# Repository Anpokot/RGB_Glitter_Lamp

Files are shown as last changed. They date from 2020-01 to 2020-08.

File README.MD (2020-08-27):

## RGB Glitter Lamp Project

### 3D Views

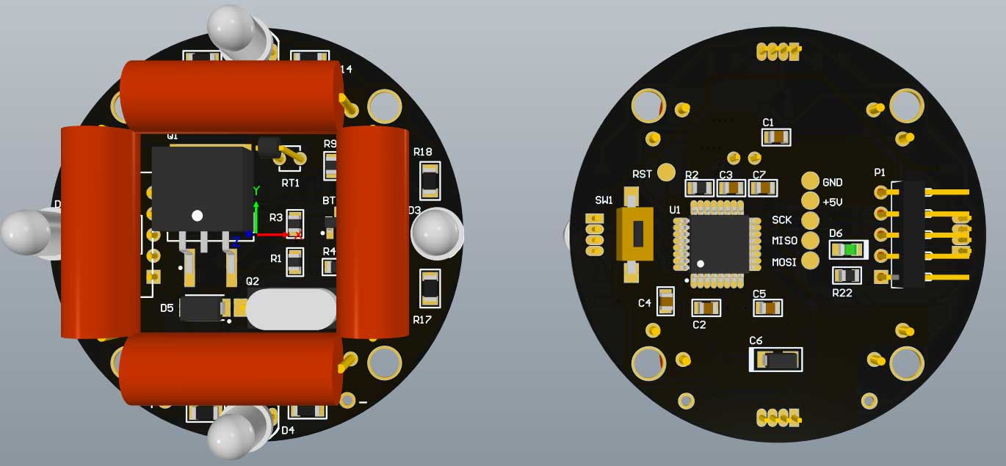
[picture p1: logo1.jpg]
</br>

### Top and Bottom View

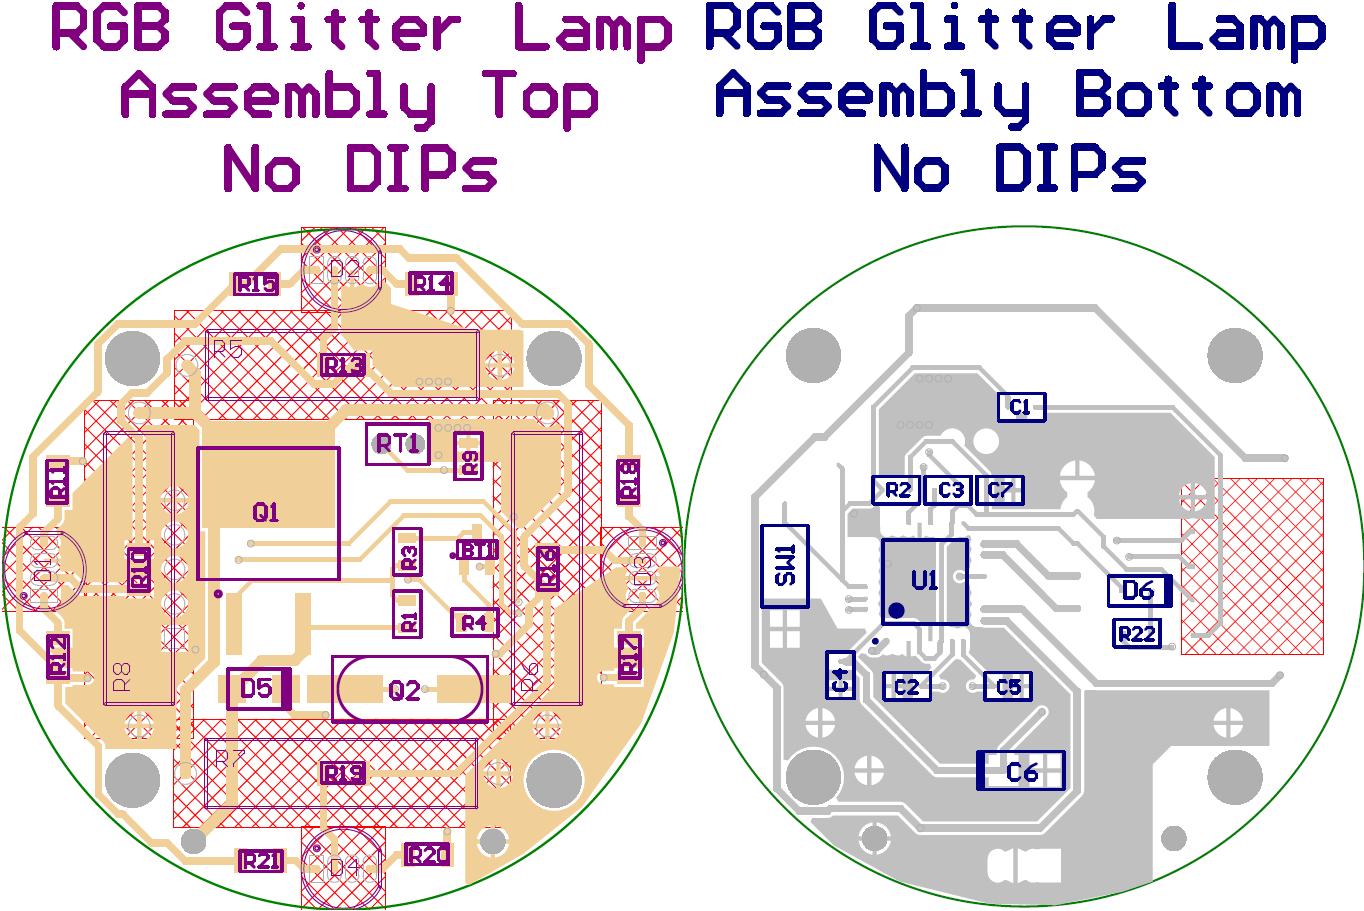
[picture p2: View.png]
</br>

### Assembly Views

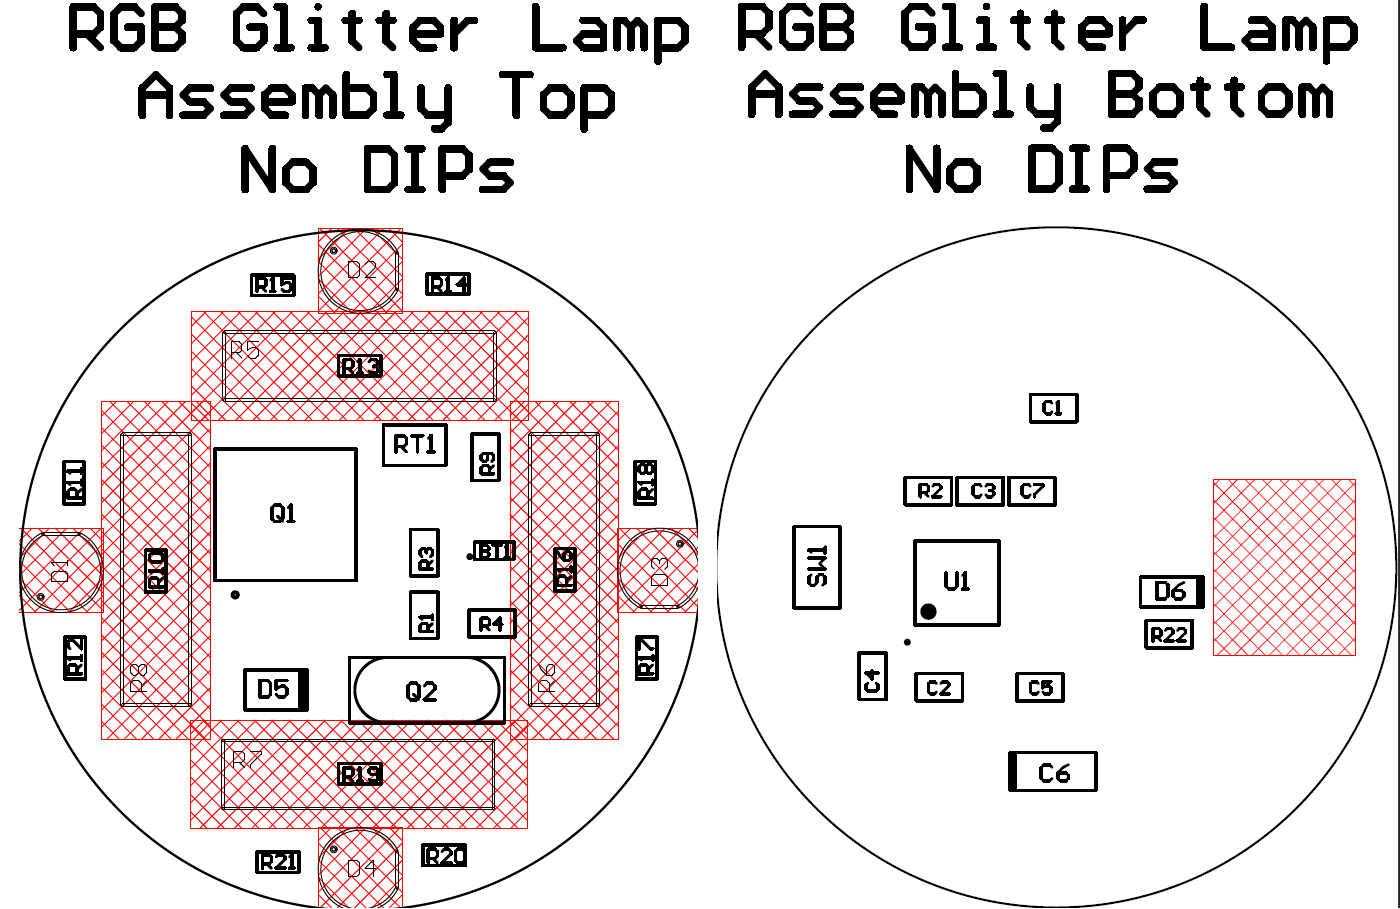
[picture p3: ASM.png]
</br>

### Mechanical Views

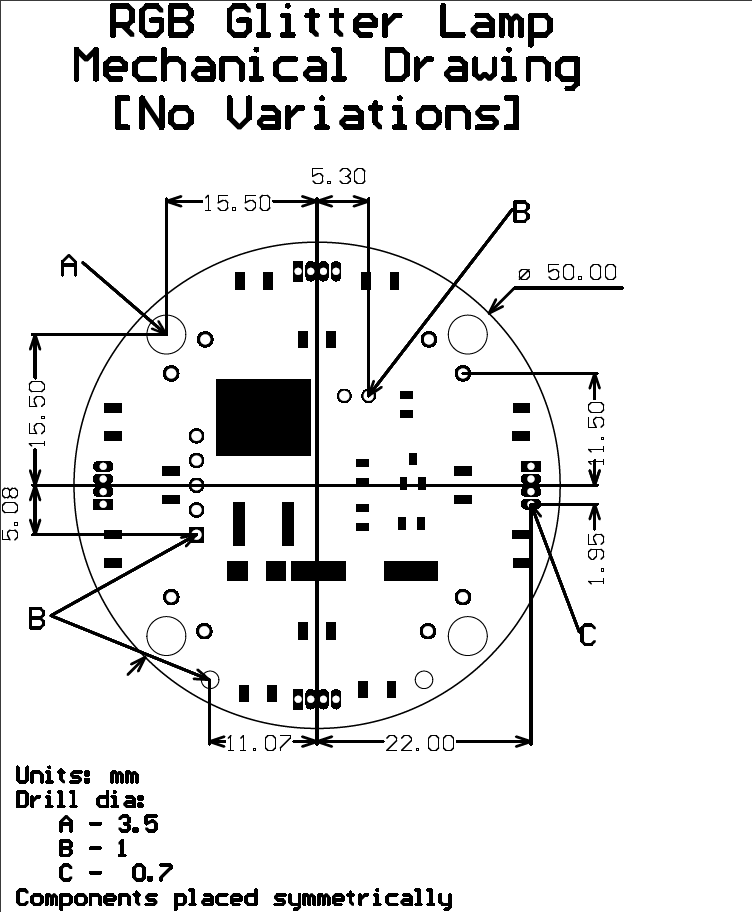
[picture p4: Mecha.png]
</br>

### Schematic

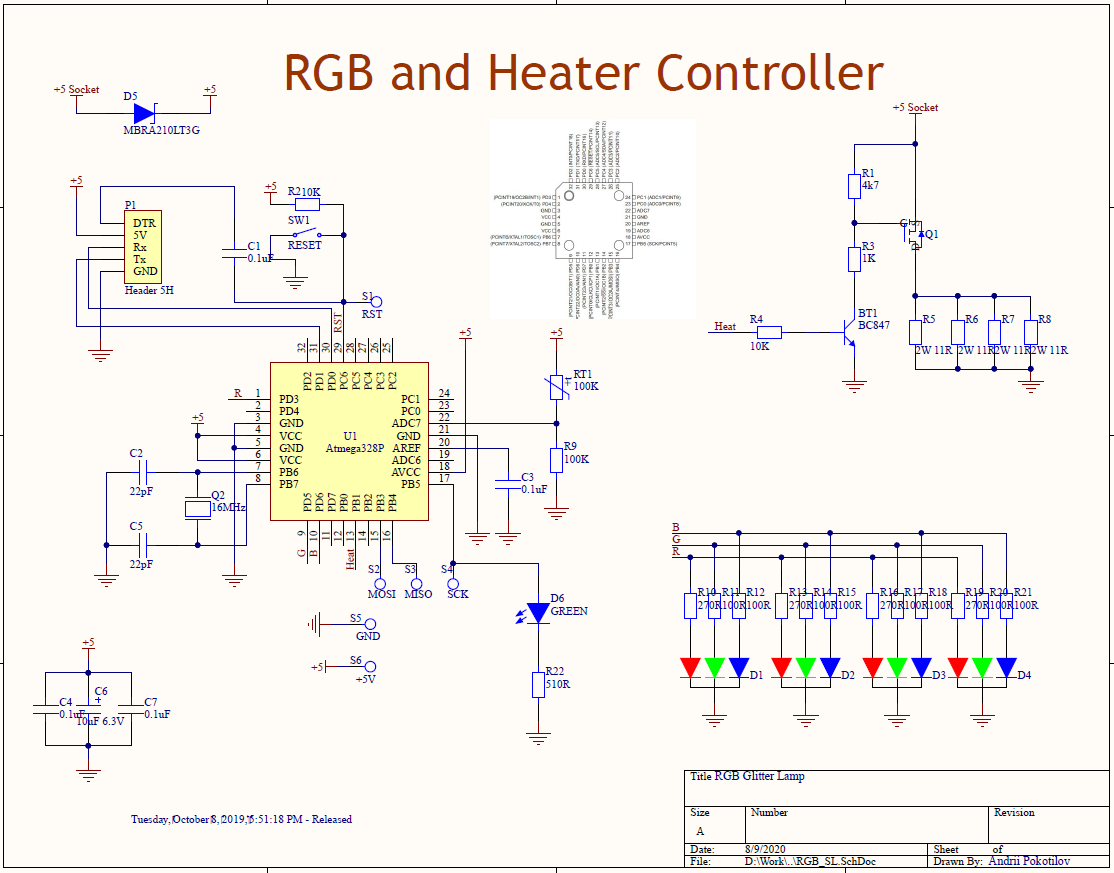
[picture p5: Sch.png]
</br>

### History

Inspiered by this video [Gillian's Diamonds lamp](https://youtu.be/PCyUxlsRoRc?t=2872) I decided to create my own version with extra features</br>

Atmega328 is used to control RGB lights and heater. 2W resistors used as a heater and thermistor provides temperature feedback</br>

Demo video of assembled prototype:</br>
Glitter Lamp Demo (https://www.youtube.com/watch?v=RdrIAsrwDjk)</br>

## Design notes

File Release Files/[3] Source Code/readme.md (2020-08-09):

## RGB Glitter Lamp Project

### Code description

ALA librarry provides defferent animations for RGB LED's </br>
Animation selection using rotary encoder with interrupts and temperature control with no delay </br>
Filtering provides valid input and allows to use low quality ecoders</br>

### Thanks to
Arduino Light Animation (ALA) library - Bruno Portaluri - bportaluri.com</br>
Robust Rotary encoder reading - John Main - best-microcontroller-projects.com

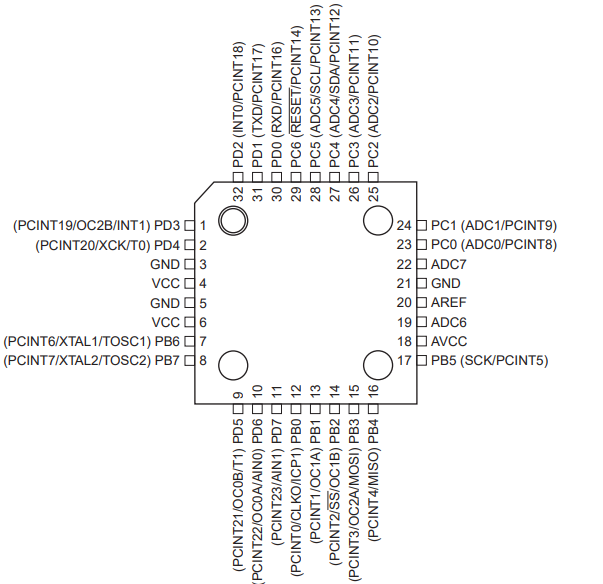
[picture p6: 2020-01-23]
Capture.PNG

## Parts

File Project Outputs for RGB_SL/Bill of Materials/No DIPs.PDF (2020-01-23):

Component | list

### Source Data From: RGB_SL.PrjPcb

Project: | RGB_SL.PrjPcb
Variant: | No DIPs
Report Date: | 11/11/2019 | 2:30:49 PM

### Print Date: 11-Nov-19 2:30:53 PM

# | Category | Manufacturer 1 | Manufacturer Part Number 1 | Case/Package | Description | Quantity

1 | Capacitors | Vishay Sprague | 293D106X96R3A2TE3 | 1206 | CAP TANT 10UF 6.3V 10% 1206 | 1
2 | Capasitors | Vishay Vitramon | VJ0805Y104KXAAT | 0805 | Ceramic Cap 0.1uF 50 V 10% MLCC - SMD/SMT | 4
3 | Capasitors | Vishay | VJ0805A220JXACW1BC | 0805 | Ceramic Cap 22 pF 50 V ±5 % Tolerance C0G/NP0 SMT Multilayer | 2
4 | Crystals | ECS International | ECS-160-20-5PX-TR | HC-49/US | CRYSTAL 16.0000MHZ 20PF SMD | 1
5 | Diodes | ON Semiconductor | MBRA210LT3G | CASE 403D SMA | DIODE SCHOTTKY 10V 2A SMA | 1
6 | Integrated Circuits | Microchip | ATMEGA328P-AUR | TQFP | IC MCU 8BIT 32KB FLASH 32TQFP | 1
7 | MOSFETs | ON Semiconductor / Fairchild | NDP6020P | TO-220AB | MOSFET P-Ch LL FET Enhancement Mode | 1
8 | NTC Thermistors | Canadian Thermostats | MF52A1104J3950 | | THERMISTOR 100K OHM 5% BEAD | 1
9 | Optoelectronics | VCC CHML | CMD17-21VGD/TR8 | 0805 | LED GREEN DIFFUSED 0805 SMD | 1
10 | Resistors | Vishay | TNPW0805100KFEEA | 0805 | RES SMD 100K Ohm 1% 0.2W(1/5W) ±25ppm/C Sulfur Resistant Conformal Coated Pad SMD Automotive Medical T/R | 1
11 | Resistors | Vishay Dale | CRCW080510K0FKTA | 0805 | RES SMD 10K OHM 1% 1/8W 0805 | 2
12 | Resistors | Vishay Dale | CRCW08051K00FKEA | 0805 | RES SMD 1K OHM 1% 1/8W 0805 | 1
13 | Resistors | Vishay | CRCW08054K70JNEAC | 0805 | RES SMD 4.7K Ohm 5% 1/8W ±200ppm/°C Molded SMD Paper T/R | 1
14 | Resistors | Vishay | CRCW0805510RFKEA | 0805 | RES SMD 510 OHM 1% 1/8W 0805 | 1
15 | Resistors | Vishay Semiconductors | CRCW1206100RFKEAC | 1206 | RES SMD 100 OHM 1% 1/4W 1206 | 8
16 | Resistors | Vishay Semiconductors | CRCW1206270RFKEAC | 1206 | RES SMD 270 OHM 1% 1/4W 1206 | 4
17 | Sw itches | TE Connectivity | FSMSMTR | SMD/SMT | SWITCH TACTILE SPST-NO 0.05A 24V | 1
18 | Transistors | Infineon | BC847AE6327HTSA1 | SOT-23-3 | Trans NPN 45V 0.1A Automotive 3-Pin SOT-23 T/R GP BJT | 1
| | | | | | 33

### Comment

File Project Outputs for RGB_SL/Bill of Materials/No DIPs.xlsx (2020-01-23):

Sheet: Part List Report
 | Component list
 | Source Data From: | RGB_SL.PrjPcb
 | Project: | RGB_SL.PrjPcb
 | Variant: | No DIPs
 | Report Date: | 10/5/2019 | 4:22:37 PM
 | Print Date: | 2019-10-05 | 16:35:53
# | Category | Manufacturer 1 | Manufacturer Part Number 1 | Case/Package | Description | Quantity
1 | Capacitors | Vishay Sprague (https://octopart-clicks.com/click/altium?sku=718-1126-1-ND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) | 293D106X96R3A2TE3 (https://octopart-clicks.com/click/altium?sku=718-1126-1-ND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) | 1206 | CAP TANT 10UF 6.3V 10% 1206 | 1
2 | Capasitors | Vishay Vitramon (https://octopart-clicks.com/click/altium?sku=720-1383-1-ND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) | VJ0805Y104KXAAT (https://octopart-clicks.com/click/altium?sku=720-1383-1-ND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) | 0805 | Ceramic Cap 0.1uF 50 V 10% MLCC - SMD/SMT | 4
3 | Capasitors | Vishay (https://octopart-clicks.com/click/altium?sku=720-1601-1-ND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) | VJ0805A220JXACW1BC (https://octopart-clicks.com/click/altium?sku=720-1601-1-ND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) | 0805 | Ceramic Cap 22 pF 50 V ±5 % Tolerance C0G/NP0 SMT Multilayer | 2
4 | Crystals | ECS International (https://octopart-clicks.com/click/altium?sku=XC1282CT-ND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) | ECS-160-20-5PX-TR (https://octopart-clicks.com/click/altium?sku=XC1282CT-ND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) | HC-49/US | CRYSTAL 16.0000MHZ 20PF SMD | 1
5 | Diodes | ON Semiconductor (https://octopart-clicks.com/click/altium?sku=MBRA210LT3GOSCT-ND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) | MBRA210LT3G (https://octopart-clicks.com/click/altium?sku=MBRA210LT3GOSCT-ND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) | CASE 403D SMA | DIODE SCHOTTKY 10V 2A SMA | 1
6 | Integrated Circuits | Microchip (https://octopart-clicks.com/click/altium?sku=ATMEGA328P-AURCT-ND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) | ATMEGA328P-AUR (https://octopart-clicks.com/click/altium?sku=ATMEGA328P-AURCT-ND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) | TQFP | IC MCU 8BIT 32KB FLASH 32TQFP | 1
7 | MOSFETs | ON Semiconductor / Fairchild (https://octopart-clicks.com/click/altium?manufacturer=ON%20Semiconductor%20%2F%20Fairchild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) | NDP6020P (https://octopart-clicks.com/click/altium?manufacturer=ON%20Semiconductor%20%2F%20Fairchild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) | TO-220AB | MOSFET P-Ch LL FET Enhancement Mode | 1
8 | Optoelectronics | VCC CHML (https://octopart-clicks.com/click/altium?sku=L62505CT-ND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) | CMD17-21VGD/TR8 (https://octopart-clicks.com/click/altium?sku=L62505CT-ND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) | 0805 | LED GREEN DIFFUSED 0805 SMD | 1
9 | Resistors | Vishay (https://octopart-clicks.com/click/altium?sku=541-3912-1-ND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) | TNPW0805100KFEEA (https://octopart-clicks.com/click/altium?sku=541-3912-1-ND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) | 0805 | RES SMD 100K Ohm 1% 0.2W(1/5W) ±25ppm/C Sulfur Resistant Conformal Coated Pad SMD Automotive Medical T/R | 1
10 | Resistors | Vishay Dale (https://octopart-clicks.com/click/altium?sku=541-3016-1-ND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) | CRCW080510K0FKTA (https://octopart-clicks.com/click/altium?sku=541-3016-1-ND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) | 0805 | RES SMD 10K OHM 1% 1/8W 0805 | 2
11 | Resistors | Vishay Dale (https://octopart-clicks.com/click/altium?sku=541-1.00KCDKR-ND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) | CRCW08051K00FKEA (https://octopart-clicks.com/click/altium?sku=541-1.00KCDKR-ND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) | 0805 | RES SMD 1K OHM 1% 1/8W 0805 | 1
12 | Resistors | Vishay (https://octopart-clicks.com/click/altium?sku=541-4165-1-ND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) | CRCW08054K70JNEAC (https://octopart-clicks.com/click/altium?sku=541-4165-1-ND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) | 0805 | RES SMD 4.7K Ohm 5% 1/8W ±200ppm/°C Molded SMD Paper T/R | 1
13 | Resistors | Vishay (https://octopart-clicks.com/click/altium?sku=541-510CCT-ND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) | CRCW0805510RFKEA (https://octopart-clicks.com/click/altium?sku=541-510CCT-ND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) | 0805 | RES SMD 510 OHM 1% 1/8W 0805 | 1
14 | Resistors | Vishay Semiconductors (https://octopart-clicks.com/click/altium?manufacturer=Vishay%20Semiconductors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) | CRCW1206100RFKEAC (https://octopart-clicks.com/click/altium?manufacturer=Vishay%20Semiconductors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) | 1206 | RES SMD 100 OHM 1% 1/4W 1206 | 8
15 | Resistors | Vishay Semiconductors (https://octopart-clicks.com/click/altium?manufacturer=Vishay%20Semiconductors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) | CRCW1206270RFKEAC (https://octopart-clicks.com/click/altium?manufacturer=Vishay%20Semiconductors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) | 1206 | RES SMD 270 OHM 1% 1/4W 1206 | 4
16 | Switches | TE Connectivity (https://octopart-clicks.com/click/altium?sku=450-1758-6-ND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) | FSMSMTR (https://octopart-clicks.com/click/altium?sku=450-1758-6-ND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) | SMD/SMT | SWITCH TACTILE SPST-NO 0.05A 24V | 1
17 | Transistors | Infineon (https://octopart-clicks.com/click/altium?sku=BC847AE6327HTSA1CT-ND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) | BC847A (https://octopart-clicks.com/click/altium?sku=BC847AE6327HTSA1CT-ND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) | SOT-23-3 | Trans NPN 45V 0.1A Automotive 3-Pin SOT-23 T/R GP BJT | 1
 |  |  |  |  |  | 32
Comment

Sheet: Project Information
Project Full Path | D:\Work\Altium\My Projects\RGB_SL\RGB_SL.PrjPcb
Project Filename | RGB_SL.PrjPcb
Variant Name | No DIPs
Data-Source Filename | RGB_SL.PrjPcb
Data-Source Full Path | D:\Work\Altium\My Projects\RGB_SL\RGB_SL.PrjPcb
Title | <Parameter Title not found>
Total Quantity | 32
Report Time | 4:22:37 PM
Report Date | 10/5/2019
Report Date & Tine | 10/5/2019 4:22:37 PM
Output Name | Bill of Materials
Output Type | BOM_PartType
Output Generator Name | BOM
Output Generator Description | Bill of Materials

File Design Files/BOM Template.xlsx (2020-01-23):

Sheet: Part List Report
 | Component list
 | Source Data From: | Field=DataSourceFileName
 | Project: | Field=ProjectFileName
 | Variant: | Field=VariantName
 | Report Date: | Field=ReportDate | Field=ReportTime
 | Print Date: | 2019-10-05 | 15:03:10
# | Column=Category | Column=Manufacturer 1 | Column=Manufacturer Part Number 1 | Column=Case/Package | Column=Description | Column=Quantity
1
2
3
 |  |  |  |  |  | 0
Comment

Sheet: Project Information
Project Full Path | Field=ProjectFullPath
Project Filename | Field=ProjectFileName
Variant Name | Field=VariantName
Data-Source Filename | Field=DataSourceFileName
Data-Source Full Path | Field=DataSourceFullPath
Title | Field=Title
Total Quantity | Field=TotalQuantity
Report Time | Field=ReportTime
Report Date | Field=ReportDate
Report Date & Tine | Field=ReportDateTime
Output Name | Field=OutputName
Output Type | Field=OutputType
Output Generator Name | Field=GeneratorName
Output Generator Description | Field=GeneratorDescription

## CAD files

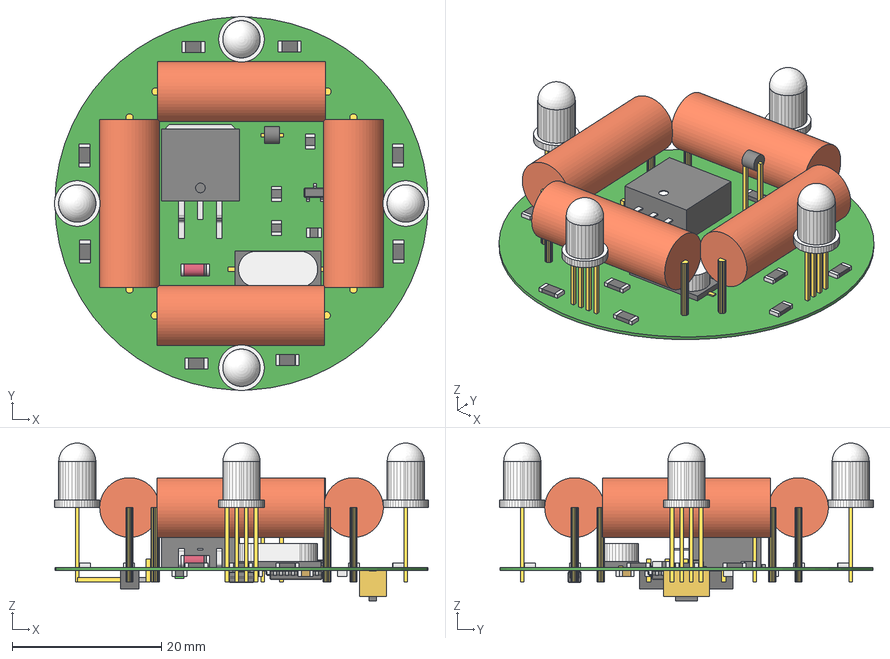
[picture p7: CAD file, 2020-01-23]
Project Outputs for RGB_SL/Export STEP/[No Variations].step
50.1 x 50.1 x 21.2 mm
Board
Open_CASCADE_STEP_translator_6.8_4.1.1
Lead x 4
Extruded x 133
Open_CASCADE_STEP_translator_6.8_25.1.1
Leader x 35
Open_CASCADE_STEP_translator_6.8_16.1
Open_CASCADE_STEP_translator_6.8_16.2.1
Open_CASCADE_STEP_translator_6.8_15.1
Open_CASCADE_STEP_translator_6.8_15.2.1
Trimmed_Lead
Open_CASCADE_STEP_translator_6.8_15.6.1

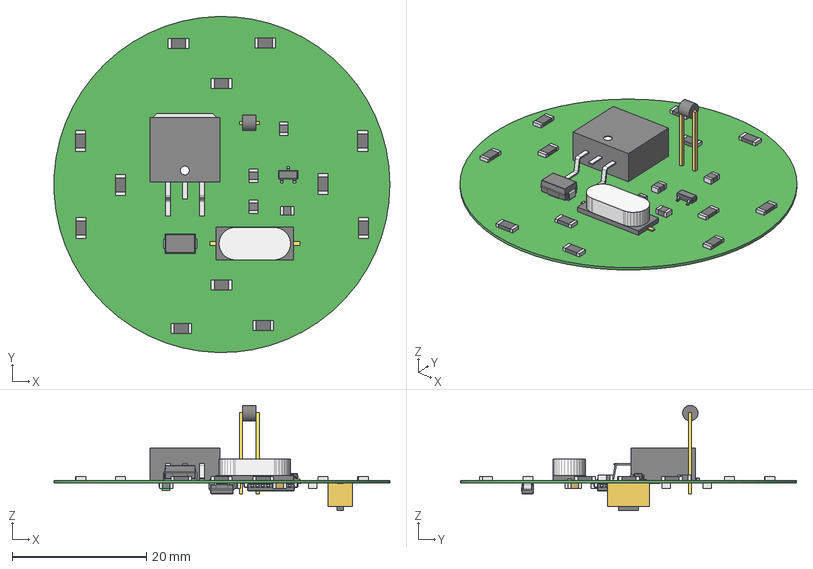
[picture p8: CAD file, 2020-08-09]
Release Files/[4] 3D/3D Model RGB Glitter Lamp No DIPs.step
50.0 x 50.0 x 15.7 mm
Extruded x 85
Open_CASCADE_STEP_translator_6.8_15.1
Open_CASCADE_STEP_translator_6.8_15.2.1
Lead x 6
Trimmed_Lead
Open_CASCADE_STEP_translator_6.8_15.6.1
Open_CASCADE_STEP_translator_6.8_16.1
Open_CASCADE_STEP_translator_6.8_16.2.1
Leader x 35
Open_CASCADE_STEP_translator_6.8_25.1.1
Open_CASCADE_STEP_translator_6.8_4.1.1
Open_CASCADE_STEP_translator_6.8_6.1.1

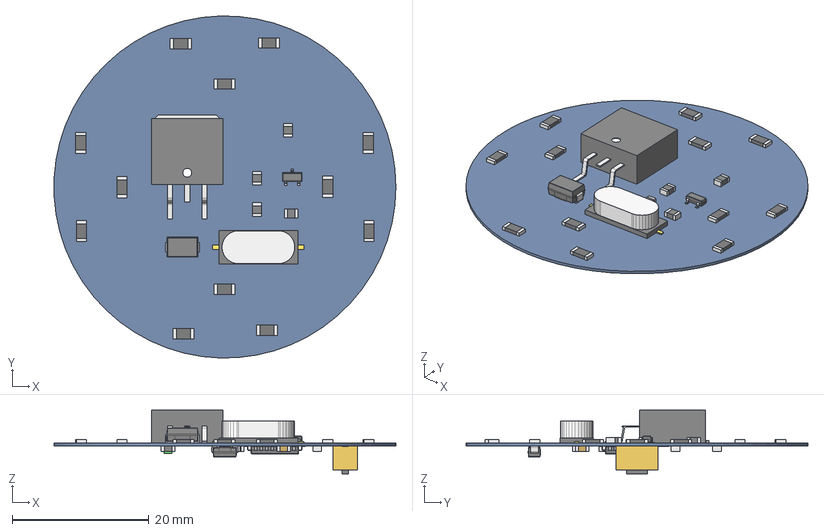
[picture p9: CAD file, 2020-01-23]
Project Outputs for RGB_SL/Export STEP/No DIPs.step
50.0 x 50.0 x 9.34 mm
Board
Open_CASCADE_STEP_translator_6.8_6.1.1
Lead x 6
Open_CASCADE_STEP_translator_6.8_4.1.1
Extruded x 83
Open_CASCADE_STEP_translator_6.8_25.1.1
Leader x 35
Open_CASCADE_STEP_translator_6.8_16.1
Open_CASCADE_STEP_translator_6.8_16.2.1
Open_CASCADE_STEP_translator_6.8_15.1
Open_CASCADE_STEP_translator_6.8_15.2.1
Trimmed_Lead
Open_CASCADE_STEP_translator_6.8_15.6.1

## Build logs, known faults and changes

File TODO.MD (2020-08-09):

- Add heater "on/off" indication led
- Design printable enclosure

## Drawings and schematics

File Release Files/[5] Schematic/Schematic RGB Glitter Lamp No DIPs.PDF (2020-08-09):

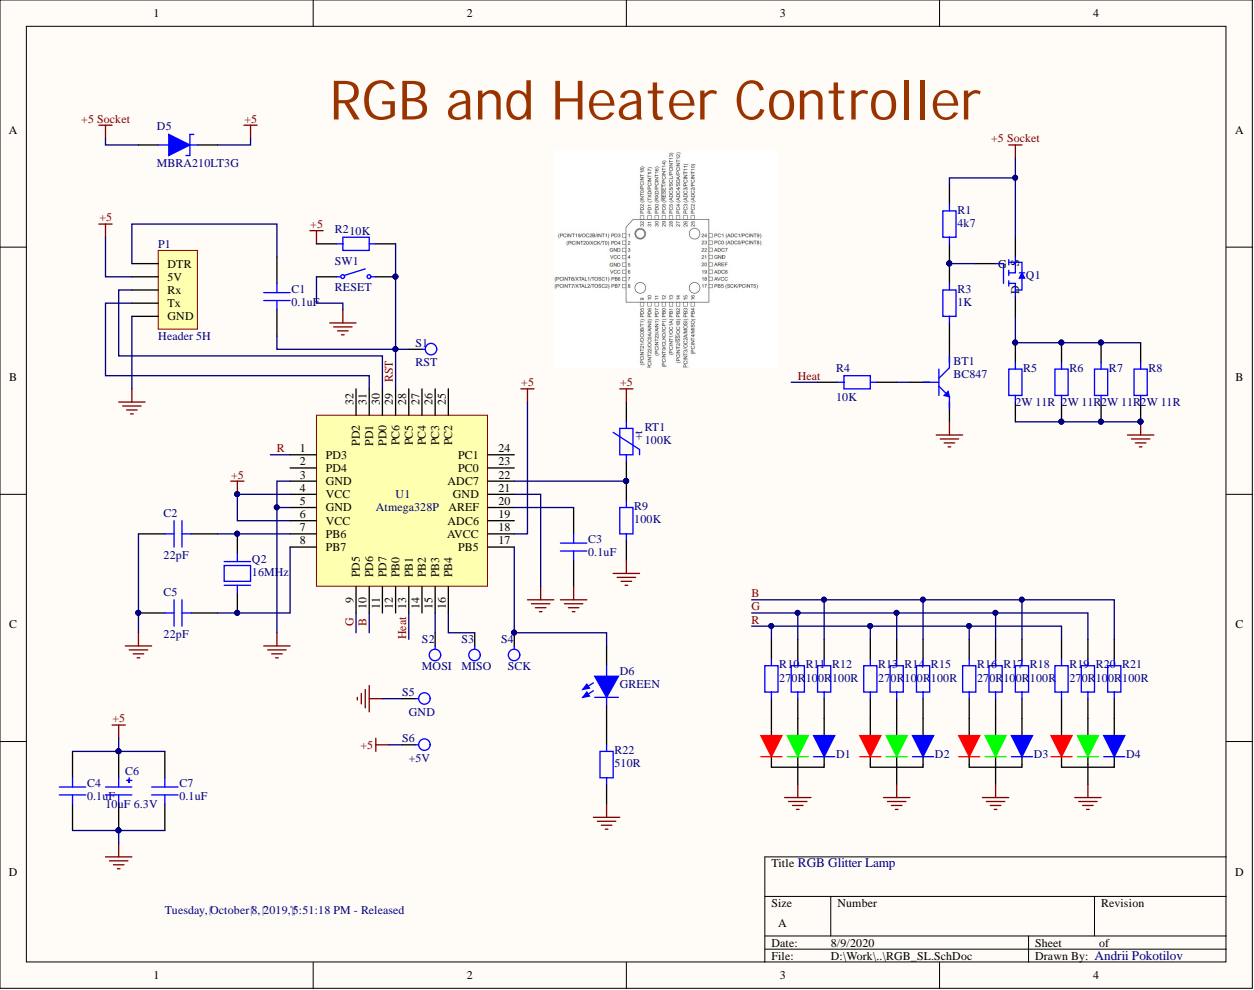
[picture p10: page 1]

RGB and Heater Controller

Tx
GND

VCC 4
GND 5
VCC 6
PB6 7
PB7 8

Tuesday, ‎October ‎8, ‎2019, ‏‎5:51:18 PM - Released

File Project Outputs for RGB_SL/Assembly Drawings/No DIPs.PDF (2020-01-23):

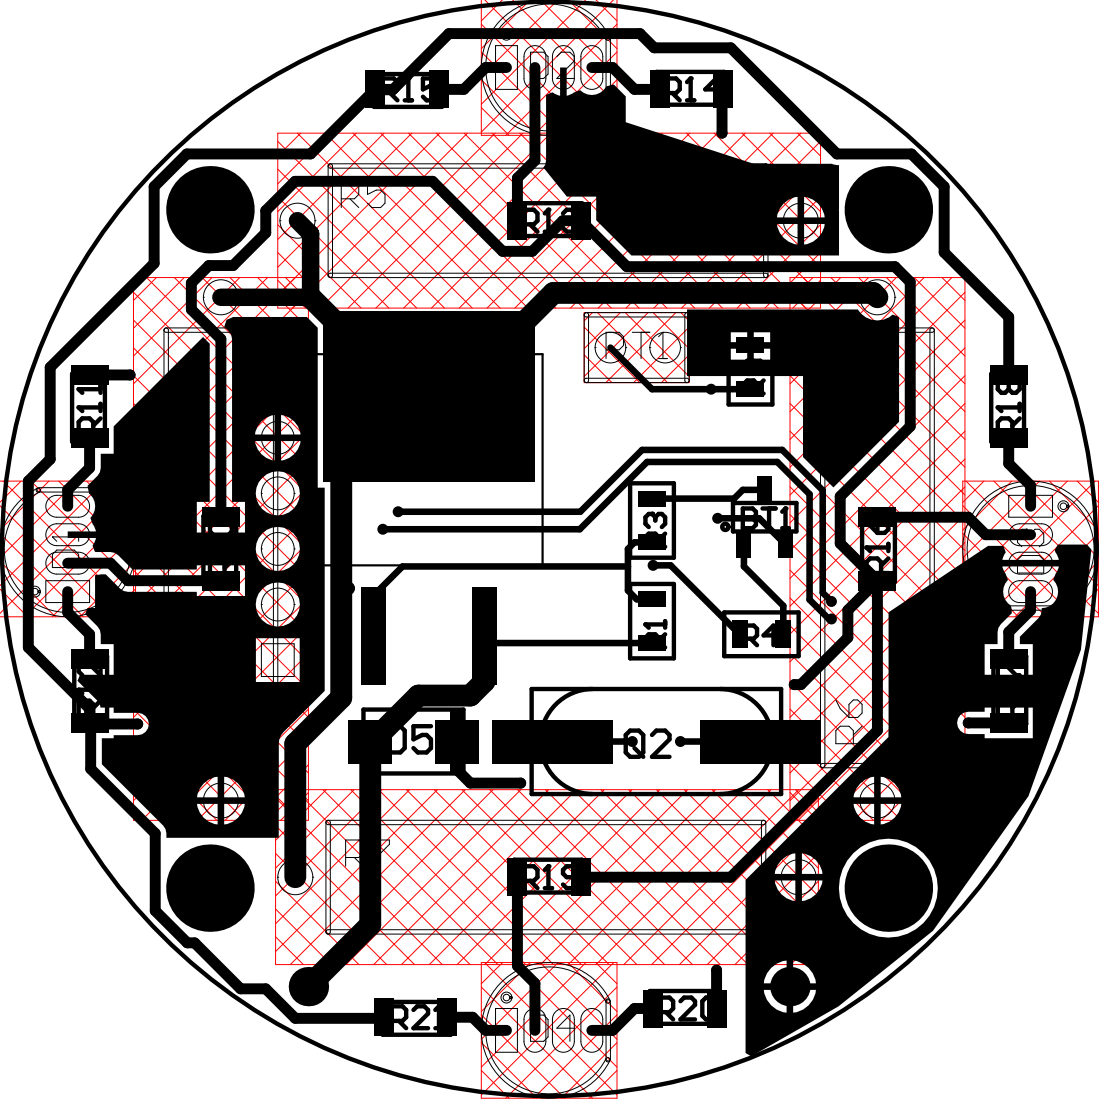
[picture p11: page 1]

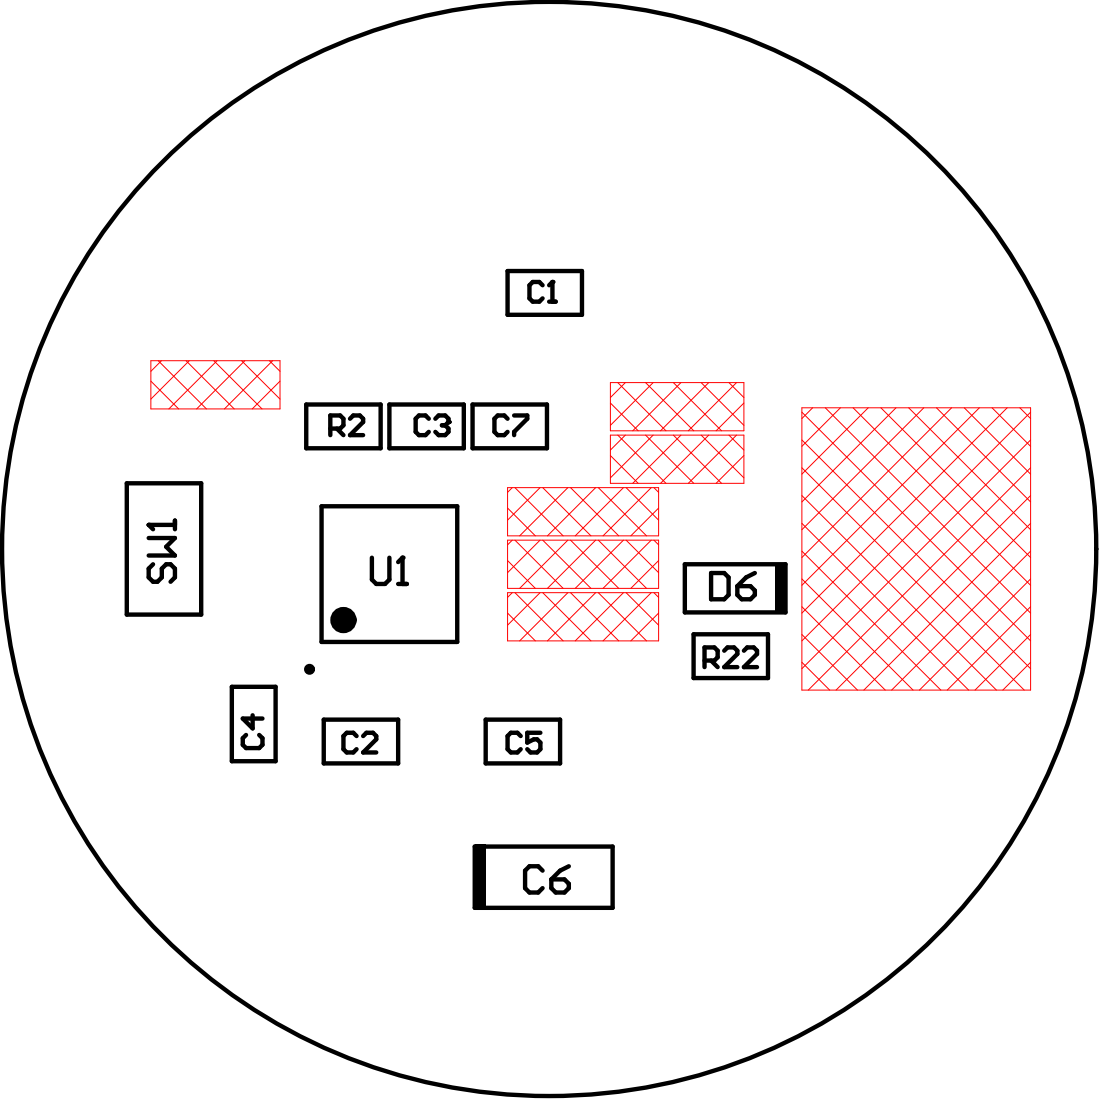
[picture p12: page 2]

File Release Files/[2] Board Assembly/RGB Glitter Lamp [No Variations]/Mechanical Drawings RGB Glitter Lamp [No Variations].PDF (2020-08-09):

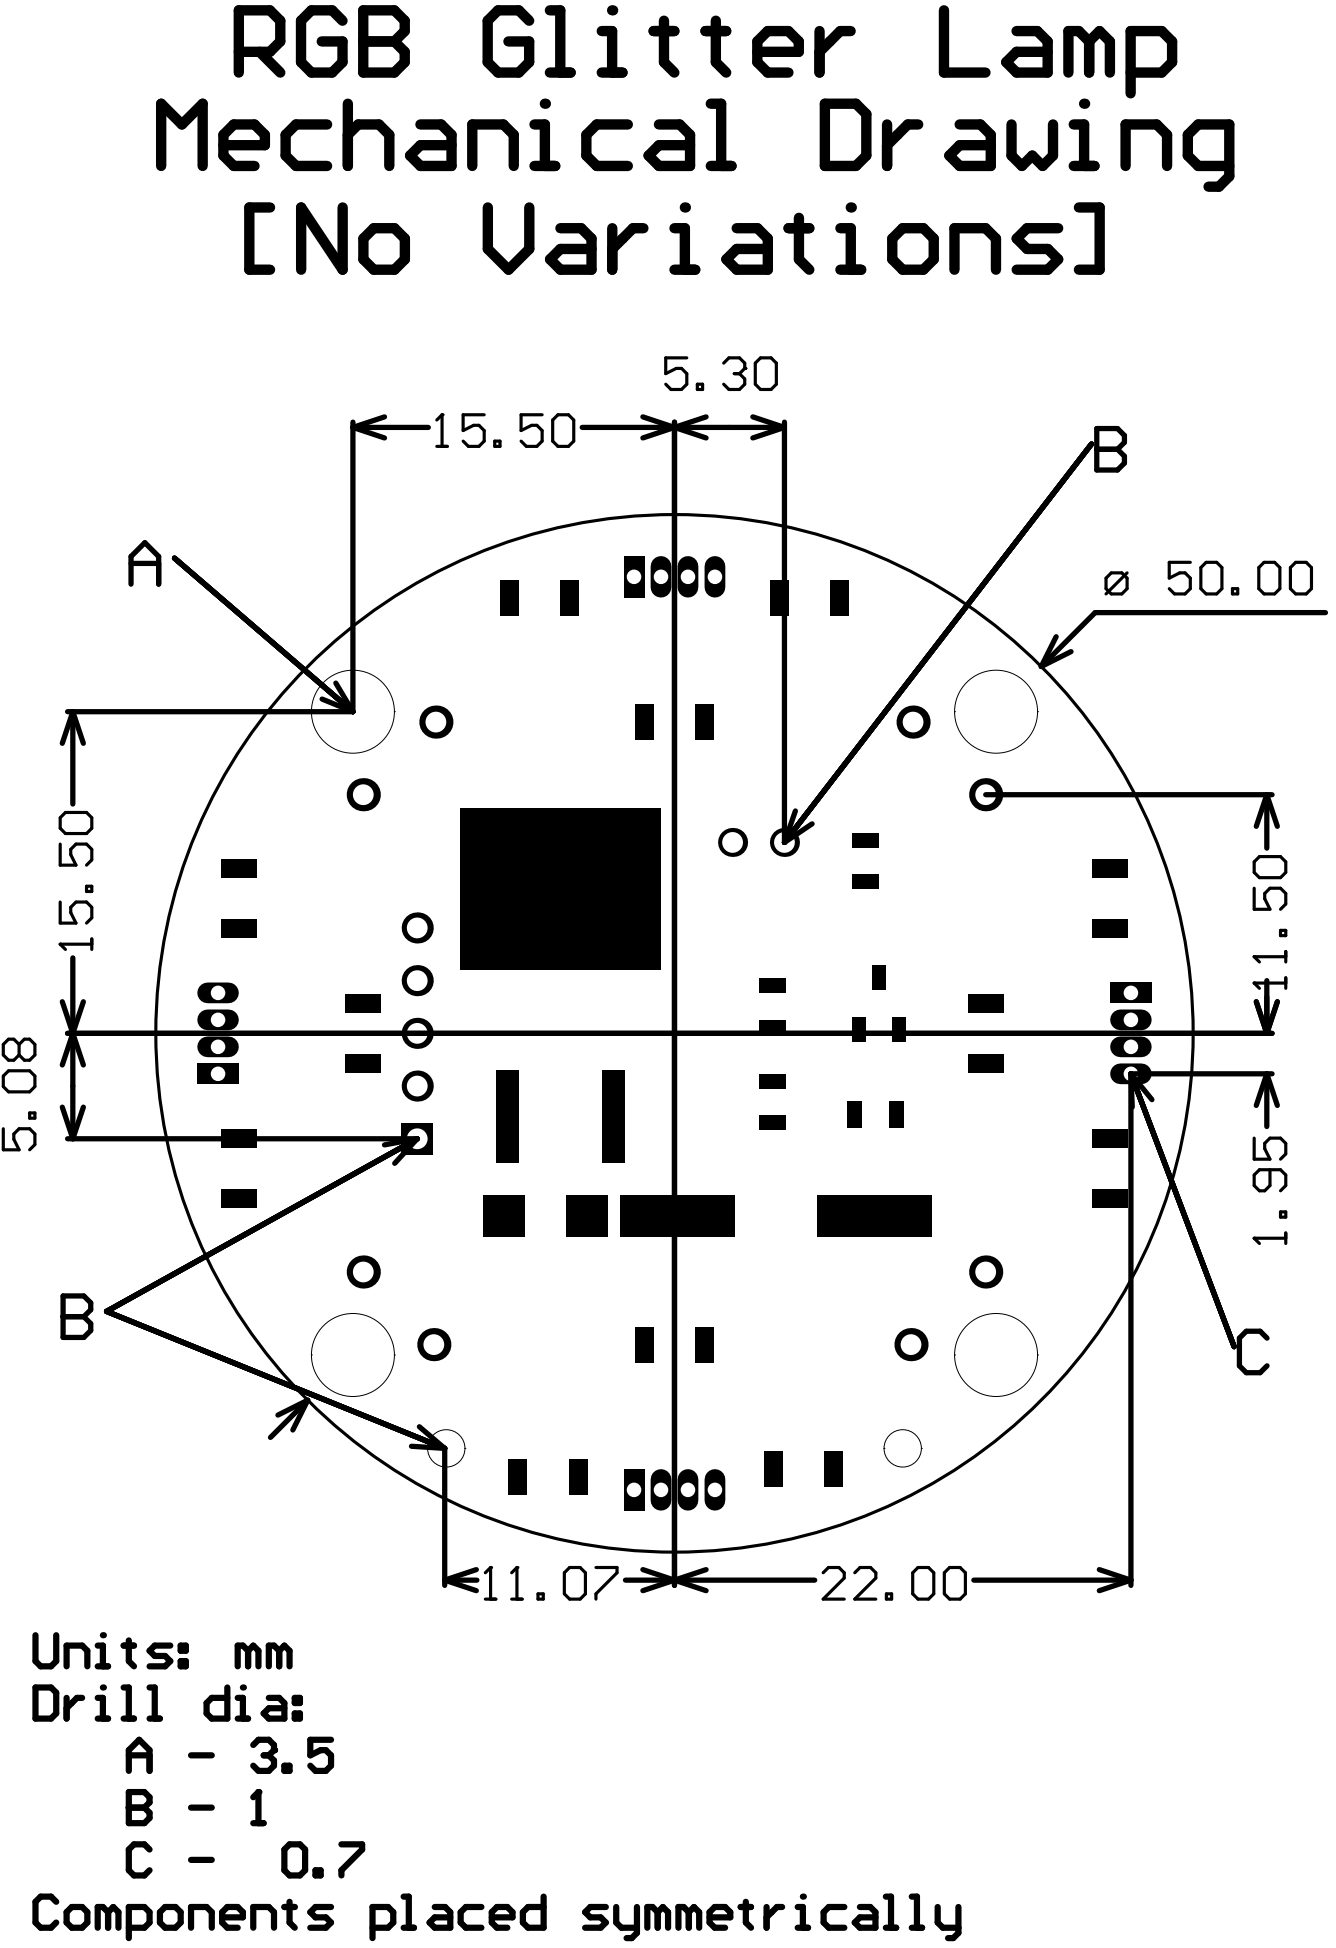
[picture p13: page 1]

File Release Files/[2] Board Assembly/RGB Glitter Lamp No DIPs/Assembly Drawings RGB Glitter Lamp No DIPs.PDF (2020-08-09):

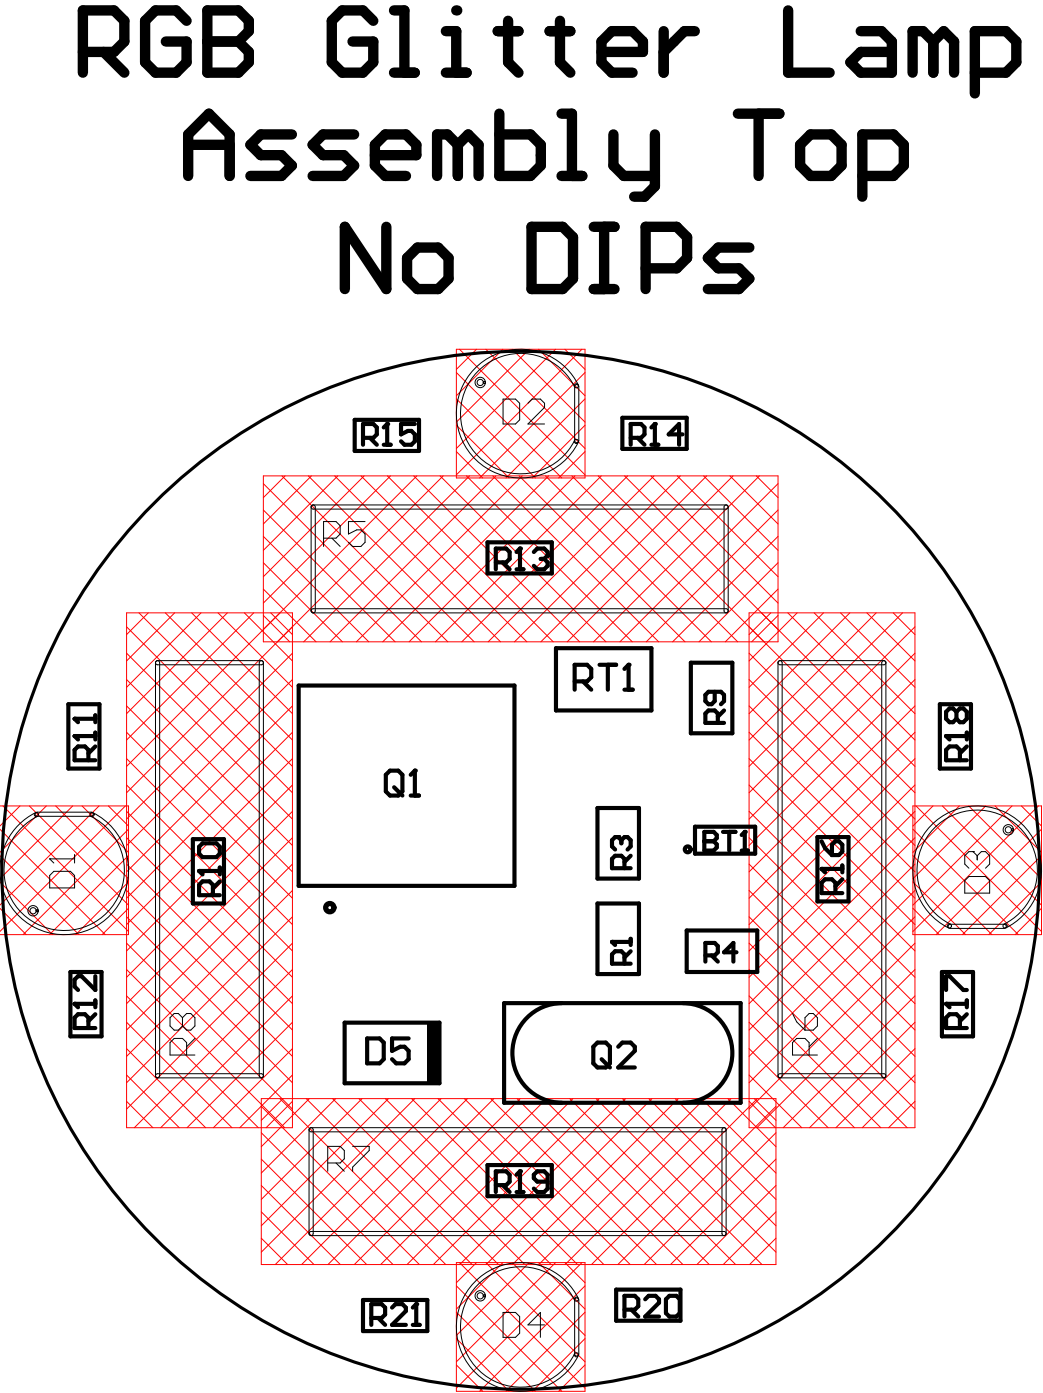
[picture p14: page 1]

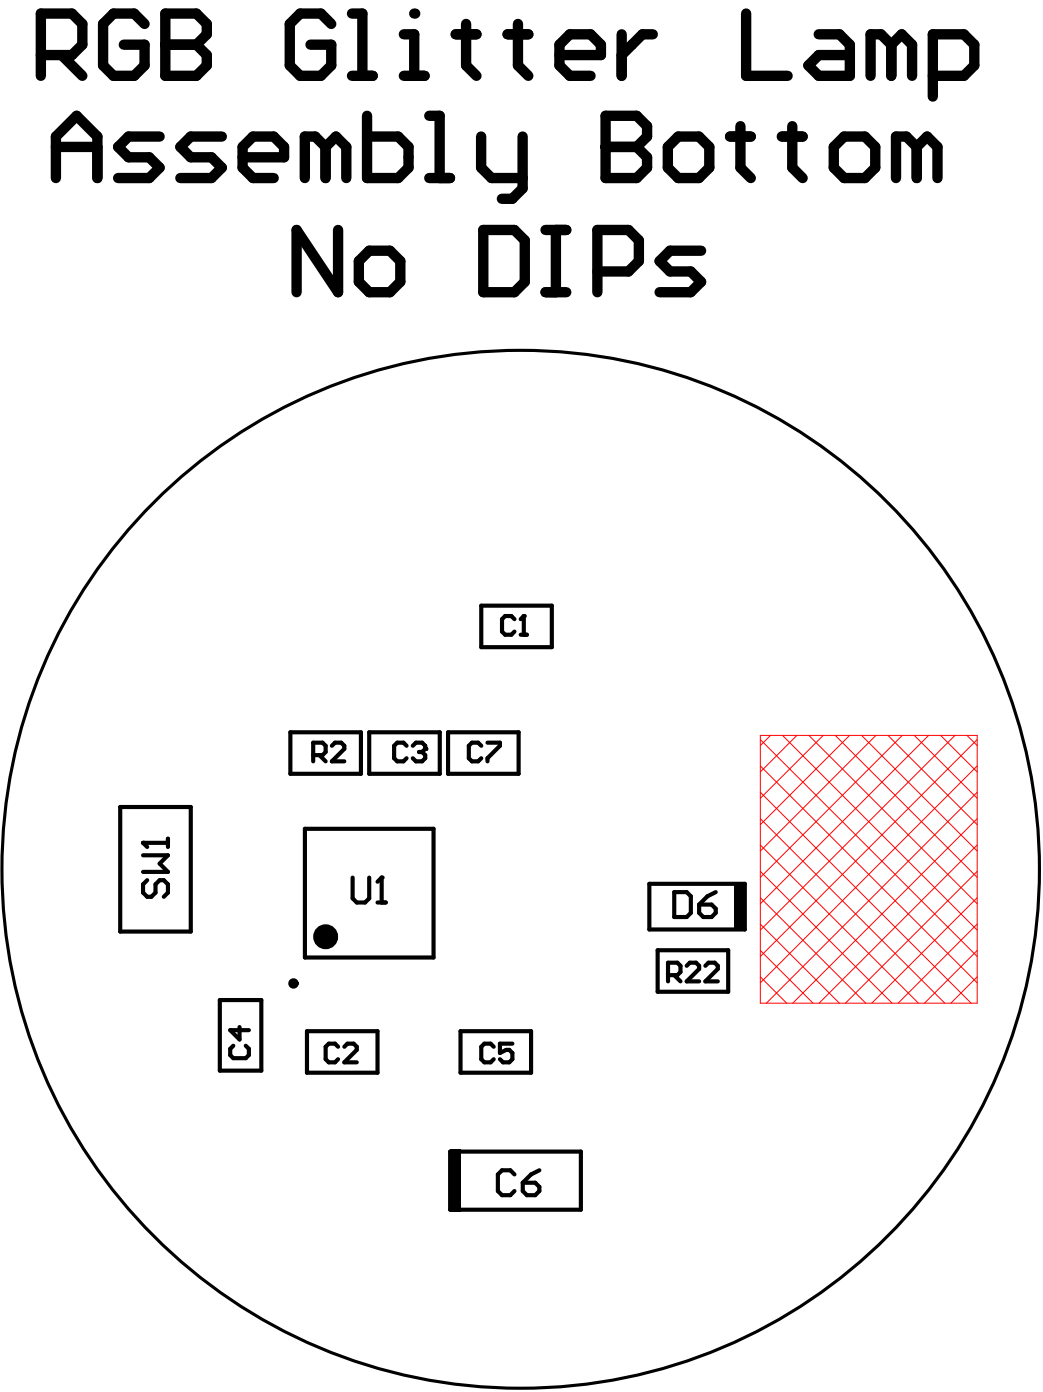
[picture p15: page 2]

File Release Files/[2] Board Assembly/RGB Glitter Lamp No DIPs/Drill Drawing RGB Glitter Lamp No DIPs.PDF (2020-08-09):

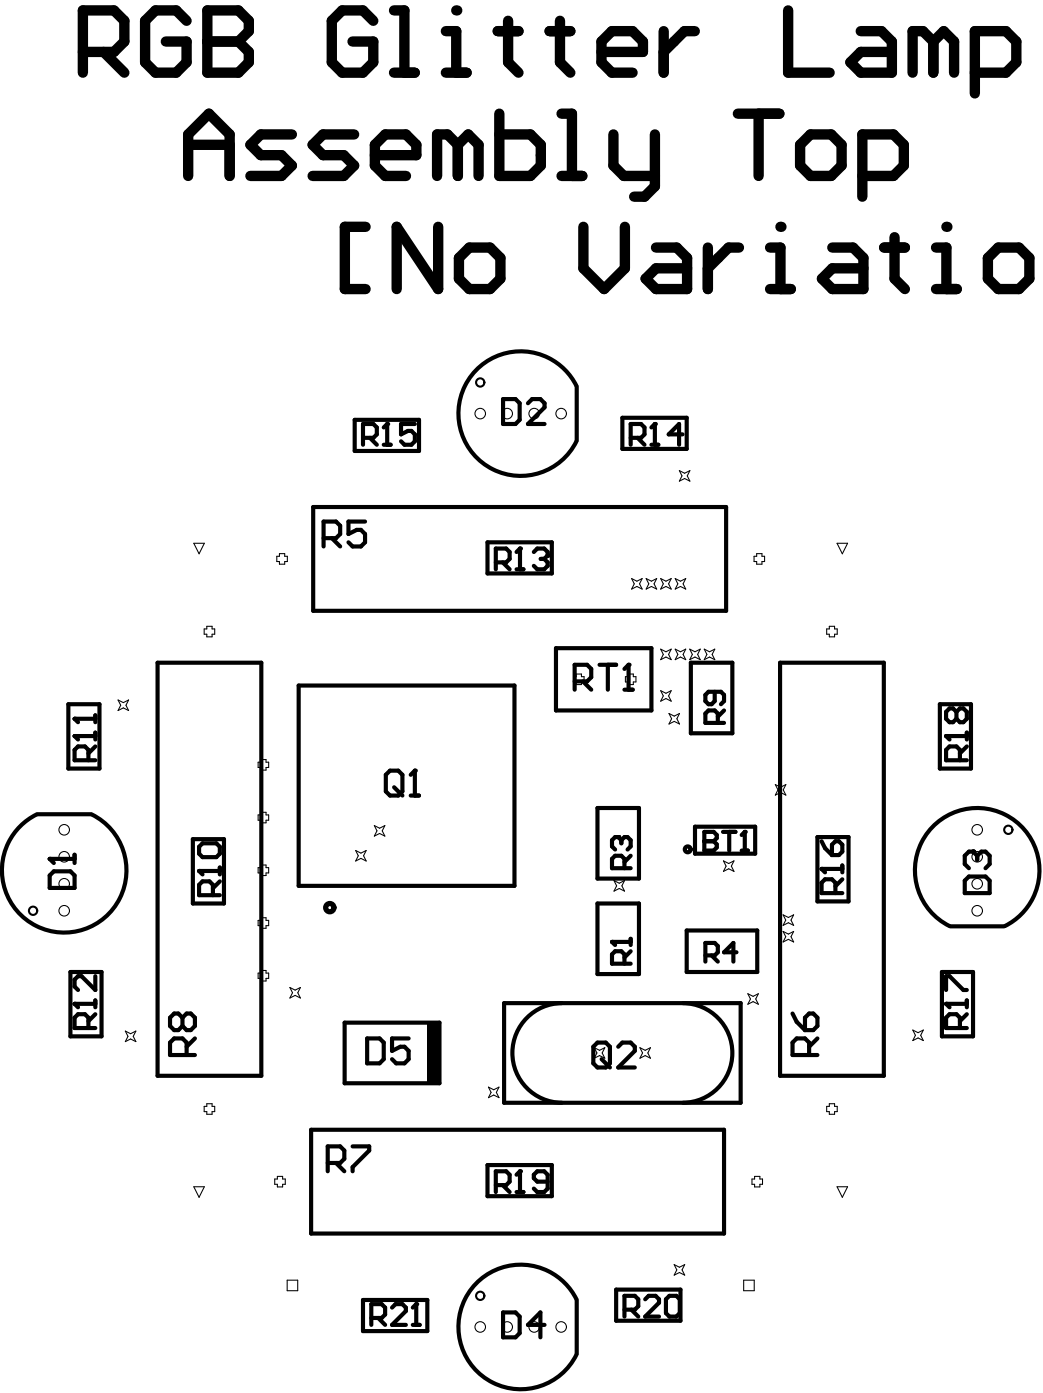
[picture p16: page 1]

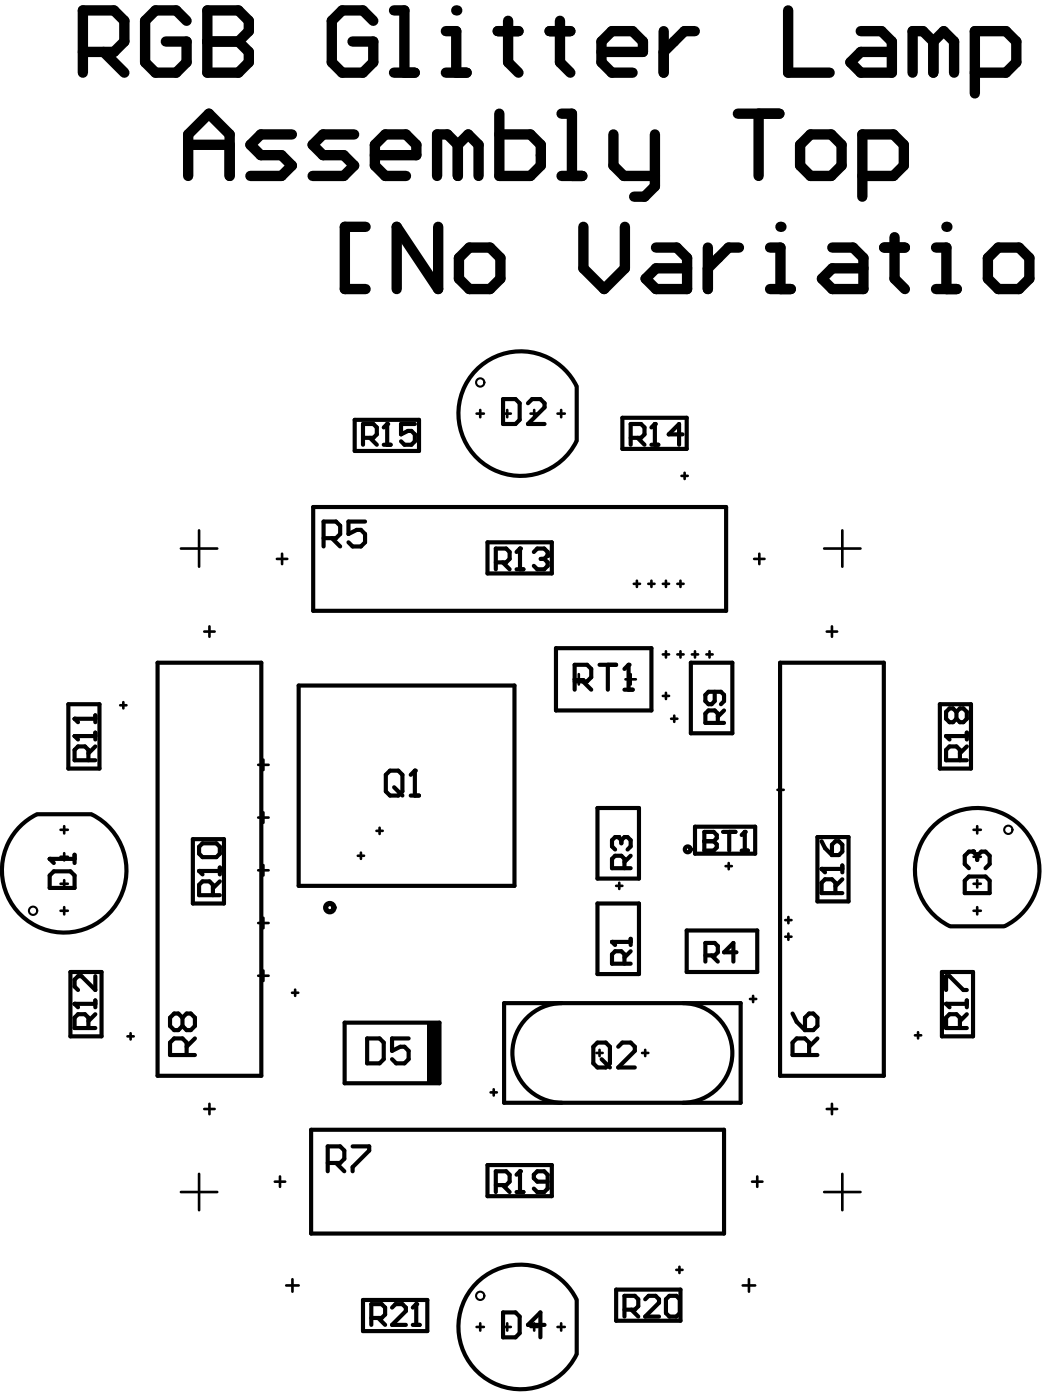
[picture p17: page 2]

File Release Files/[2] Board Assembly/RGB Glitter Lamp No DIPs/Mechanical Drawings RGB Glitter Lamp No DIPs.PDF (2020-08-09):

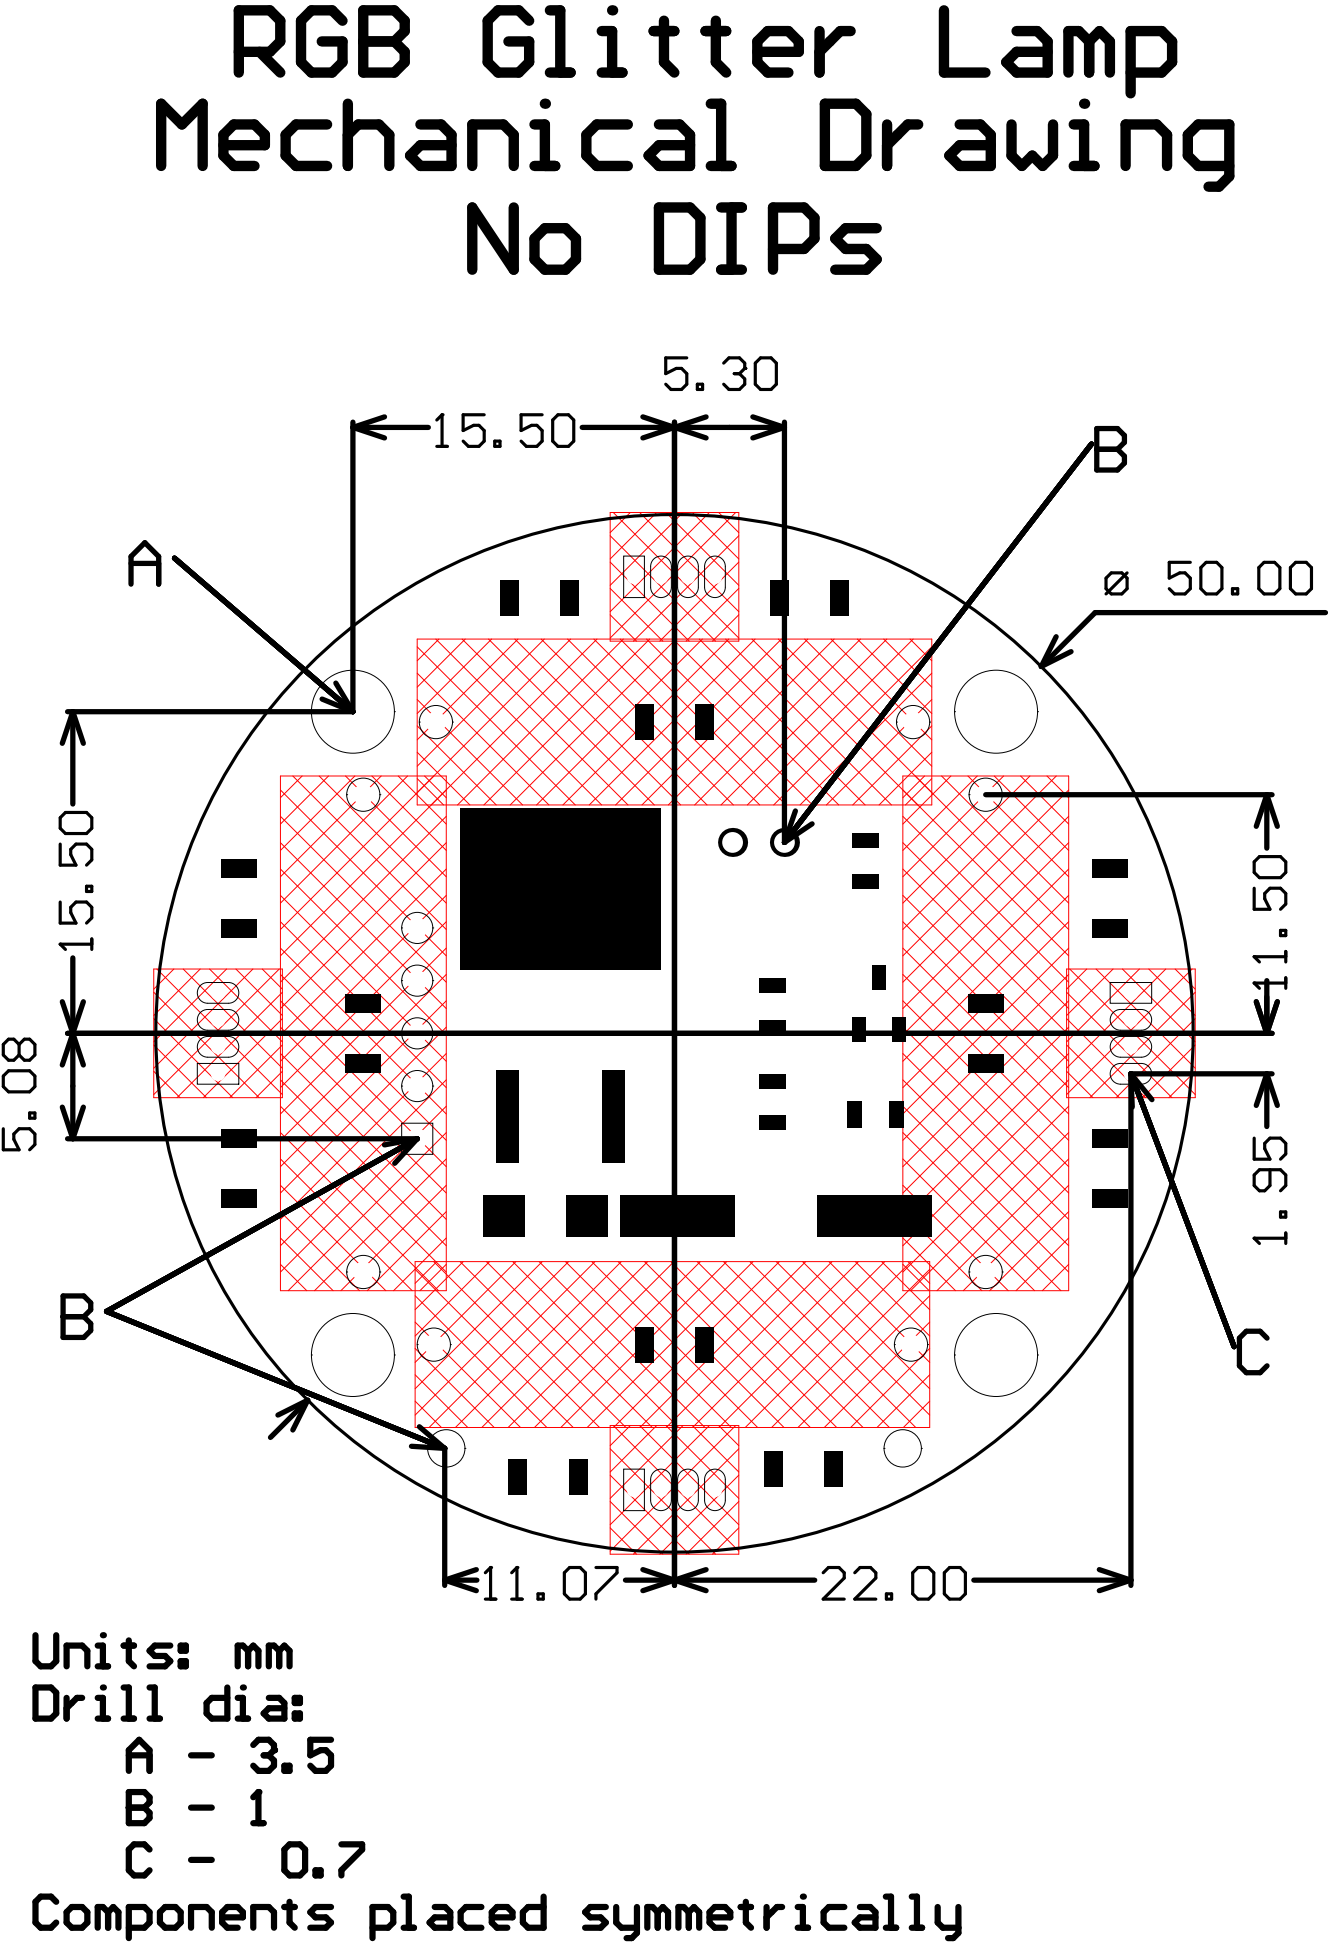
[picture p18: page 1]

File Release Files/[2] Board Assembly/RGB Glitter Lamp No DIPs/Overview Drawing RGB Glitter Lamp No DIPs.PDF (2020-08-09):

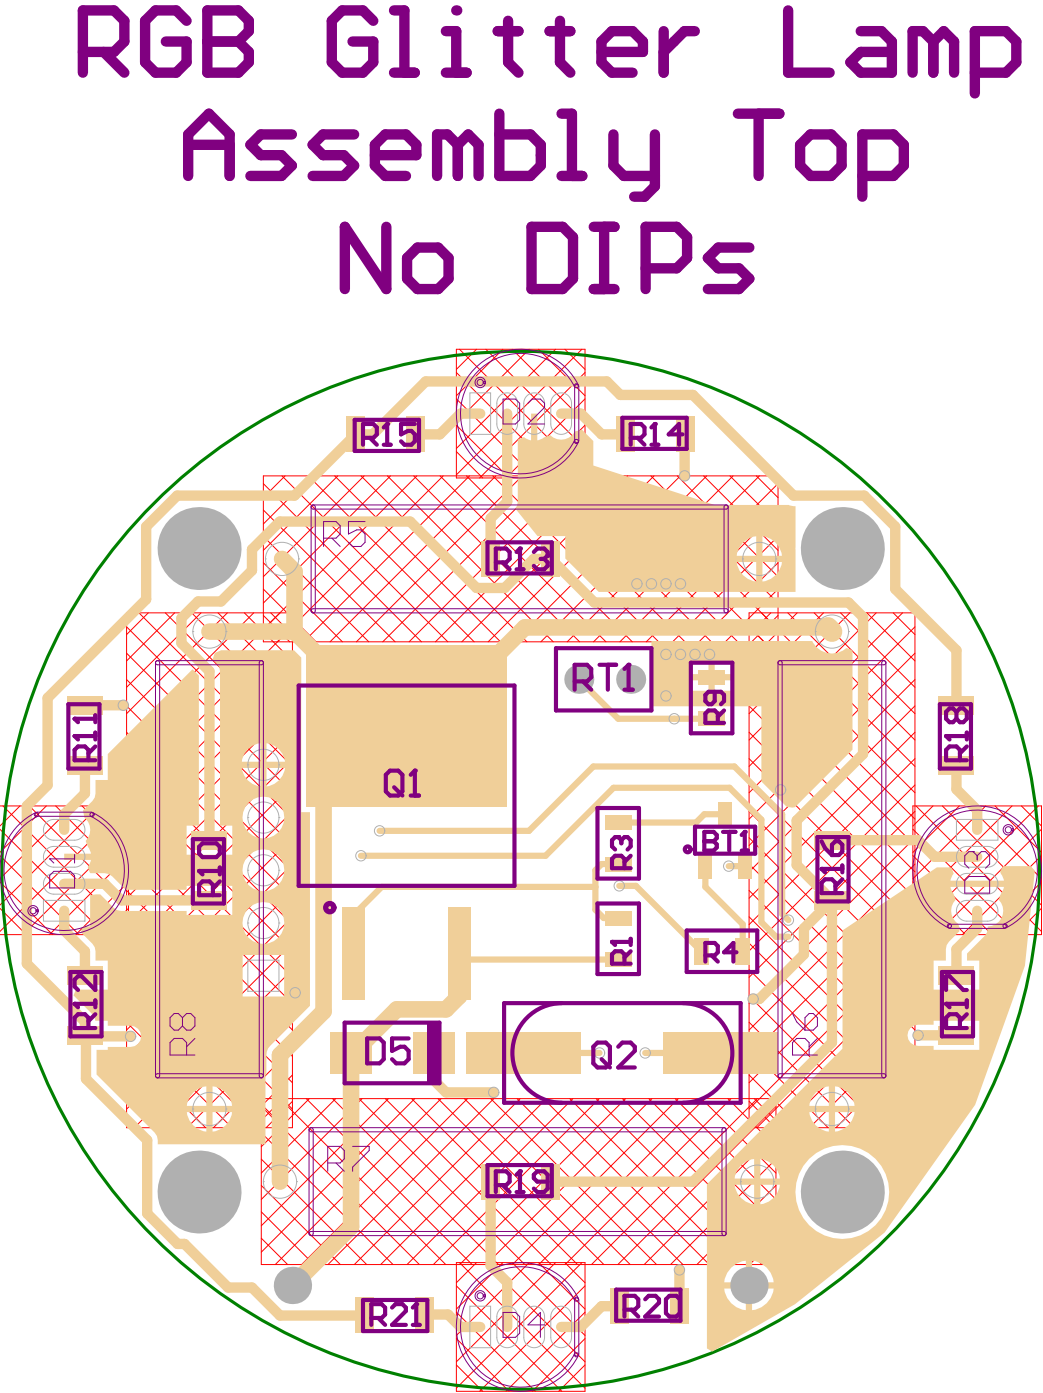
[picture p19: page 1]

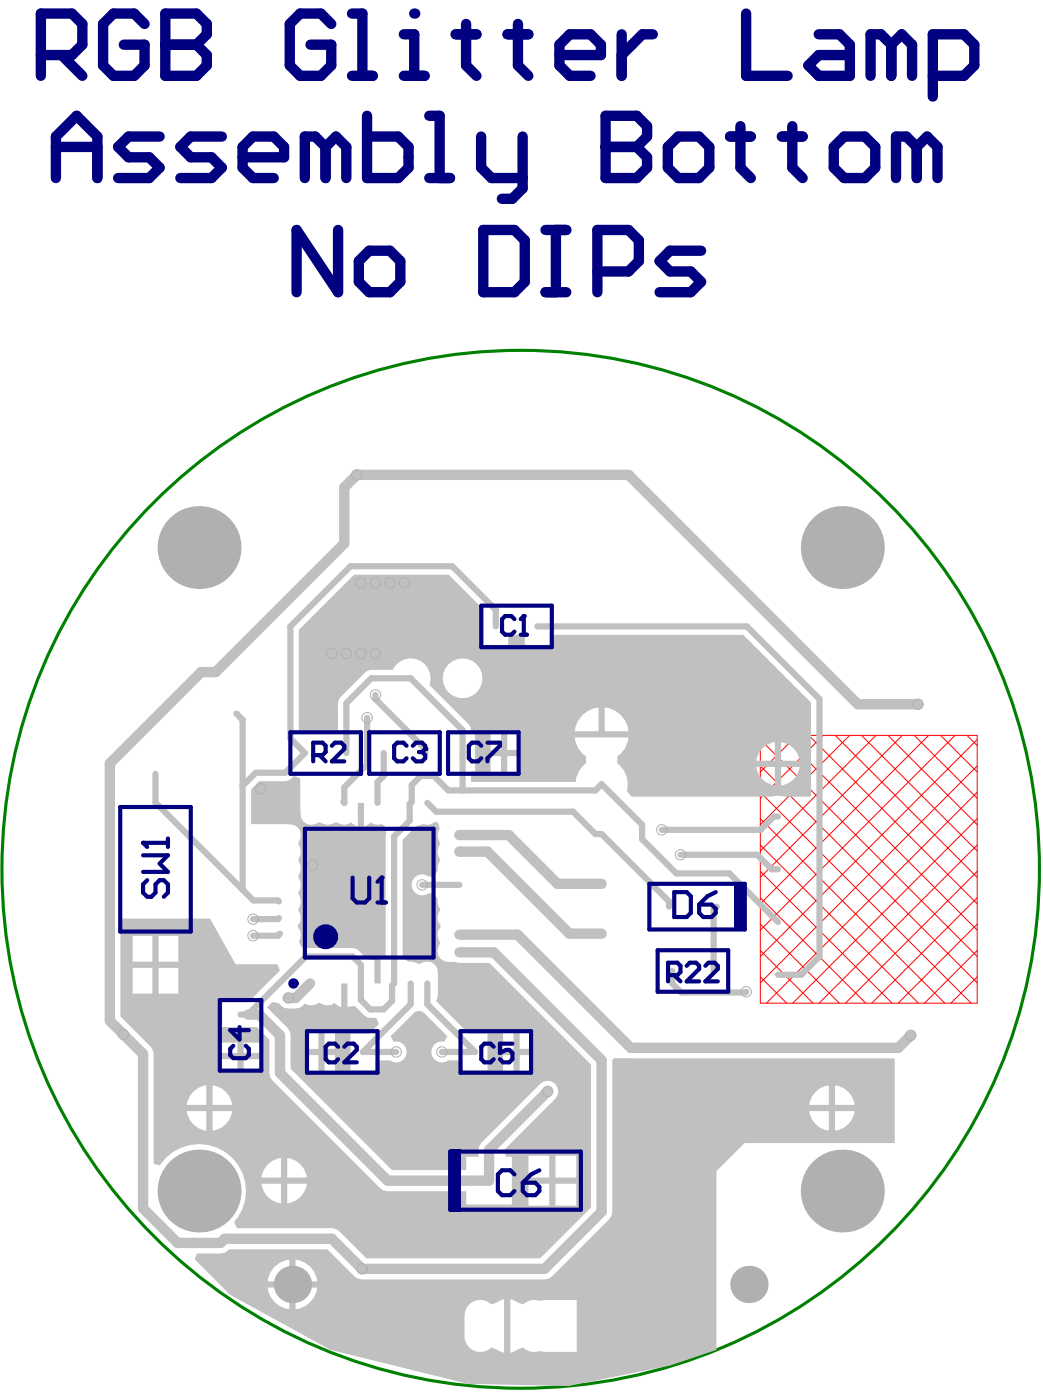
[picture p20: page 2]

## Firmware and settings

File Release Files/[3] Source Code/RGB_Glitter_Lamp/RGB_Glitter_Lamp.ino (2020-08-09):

#include "AlaLedRgb.h"

// Arduino Light Animation (ALA) library - Copyright Bruno Portaluri - bportaluri.com
//
// Robust Rotary encoder reading - Copyright John Main - best-microcontroller-projects.com
//

#define CLK 11
#define DATA 12
#define Rpin 5
#define Gpin 3
#define Bpin 6
#define T A7 //Thermistor pin
#define Butt 2
#define Heat 9 //Heater pin 

int lim = 820; //Temp limiter
long k =0;

AlaLedRgb rgbLed;

// custom palette :         black     white     black     red       green     blue
AlaColor mycolors_[6] = { 0x000000, 0xFFFFFF, 0x000000, 0xFF0000, 0x00FF00, 0x0000FF };
AlaPalette mycolors = { 6, mycolors_ };


AlaSeq seq[] =
{
  { ALA_CYCLECOLORS, 3000, 3000, alaPalRgb },
  { ALA_OFF, 1000, 1000, alaPalNull },
  { ALA_FADECOLORSLOOP, 4000, 8000, alaPalRgb },
  { ALA_FADECOLORSLOOP, 500, 4000, mycolors },
  { ALA_OFF, 1000, 1000, alaPalNull },
  { ALA_FADECOLORS, 5000, 5000, mycolors },
  { ALA_OFF, 1000, 1000, alaPalNull },
  { ALA_ENDSEQ }
};

void setup() {
  pinMode(CLK, INPUT);
   pinMode(CLK, INPUT_PULLUP);
  pinMode(DATA, INPUT);
   pinMode(DATA, INPUT_PULLUP);
  pinMode(Butt, INPUT);
  pinMode(T, INPUT);
  pinMode(Heat, OUTPUT);
  pinMode(Rpin, OUTPUT);
  pinMode(Gpin, OUTPUT);
  pinMode(Bpin, OUTPUT);
  Serial.begin (9600);
  attachInterrupt (digitalPinToInterrupt(Butt),SIR,RISING);
   
  rgbLed.initPWM(Rpin, Gpin, Bpin); // initialize the RGB LED
  rgbLed.setBrightness(0x66FF44); // set the brightness of the LED calibrating white
  rgbLed.setAnimation(ALA_FADECOLORSLOOP, 10000, alaPalRgb);
}

static uint8_t prevNextCode = 0;
static uint16_t store=0;
static int8_t val;
static int8_t c =0;



void SIR() {
  while(1){
    k++;
    
      if(val=read_rotary() ){
      c +=val;
      Serial.print("val= ");Serial.println(val);
      delay(1);
        if(c>=3) c=0;
        if(c<=-1) c=2;
      Serial.println(c);
      k=0;  
      break;      
    }
      if(k>80000){
        k=0;
        break;
        }
   }
}





void loop() {
tempcheck();
//delay(1000);

  switch(c){
    case 0:
      digitalWrite(Rpin, HIGH);
      digitalWrite(Gpin, HIGH);
      digitalWrite(Bpin, HIGH);
   
    break;
   case 1:
      rgbLed.setAnimation(ALA_FADECOLORSLOOP, 10000, alaPalRgb);
      rgbLed.runAnimation();
   
    break;
   case 2:
      rgbLed.setAnimation(ALA_CYCLECOLORS, 10000, alaPalRgb);
      rgbLed.runAnimation();
   
      break;
    }
  
}

static int8_t read_rotary() { // A vald CW or CCW move returns 1, invalid returns 0.
  static int8_t rot_enc_table[] = {0,1,1,0,1,0,0,1,1,0,0,1,0,1,1,0};

  prevNextCode <<= 2;
  if (digitalRead(DATA)) prevNextCode |= 0x02;
  if (digitalRead(CLK)) prevNextCode |= 0x01;
  prevNextCode &= 0x0f;

   // If valid then store as 16 bit data.
   if  (rot_enc_table[prevNextCode] ) {
      store <<= 4;
      store |= prevNextCode;
      //if (store==0xd42b) return 1;
      //if (store==0xe817) return -1;
      if ((store&0xff)==0x2b) return -1;
      if ((store&0xff)==0x17) return 1;
   }
   return 0;
}

void tempcheck(){
  k++;
  if(analogRead(T)>=lim){
          if(k>100){
      digitalWrite(Heat,LOW);
      k=0;
      }
    }
    else {
      if(k>100){
        digitalWrite(Heat,HIGH);
        k=0;
      }
    }
  Serial.println(analogRead(T));  
}
  

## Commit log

2020-05-26 Adding missing libs
    [MainBLib.PcbLib, MainBLib.SchLib, RGB_SL.PcbDoc]
2020-08-09 README update
    [3D Model RGB Glitter Lamp No DIPs.step, BOM Template.xlsx, MainBLib.PcbLib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]
